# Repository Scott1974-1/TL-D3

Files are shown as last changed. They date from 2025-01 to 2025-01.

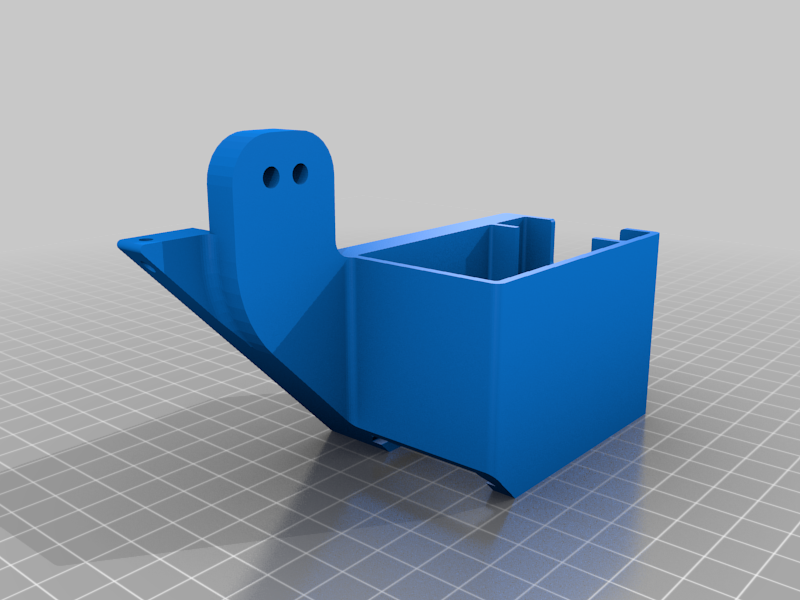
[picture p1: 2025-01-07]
Useful STL Files for the TL-D3 Pro /Purge Bin w_ Modular Inserts/images/TLD3pro_Purge_Bin.png

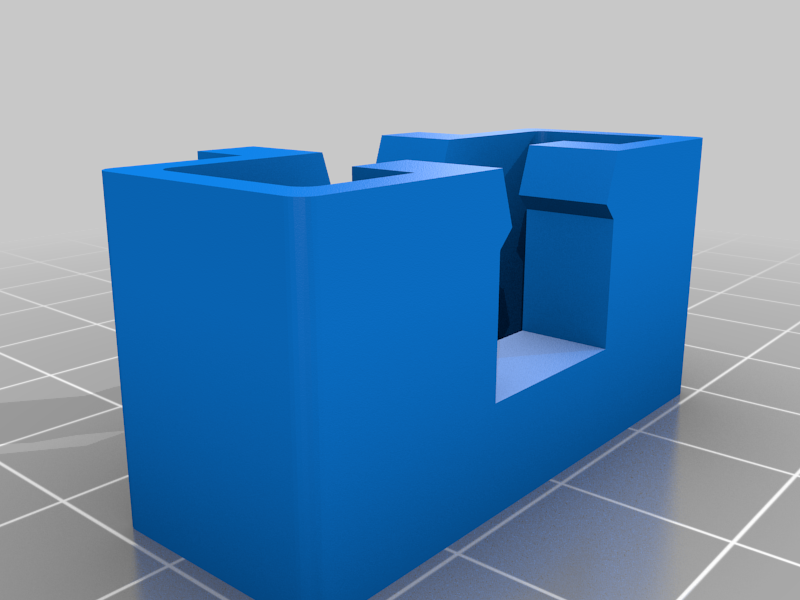
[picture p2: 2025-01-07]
Useful STL Files for the TL-D3 Pro /Purge Bin w_ Modular Inserts/images/TLD3pro_Purge_Bin_Brush_Insert.png

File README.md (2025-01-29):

# TL-D3 BUILD

This project will be coverting a stock Tenlog TL-D3 IDEX 3D printer into a fully upgraded machine running on Klipper firmware.<br>
The information collected in the GitHub is compiled from many different locations on the internet.<br>
The intent will be to build as complete of a collection of files, data and resources that are required to complete this project.<br>
<br><br><br>
Hardware used for this build:<br>
<br>
MCU = BTT Octopus Pro v1.1<br>
Steppers = 2209 v1.2<br>
CPU = Raspberry Pi 4b with 8GB ram & 256GB Sandisk Extreme Pro MicroSD Card<br>
Chassis = TenLog TLD3 Pro<br>
Display = TFT35 HDMI 3.5" touch screen<br>
Power = 24V Meanwell PS<br>
Camera = Logitech C270<br>
<br><br><br>
This will include the following upgrades:<br>
<br>
1- BTT Octopus Pro v1.1 MCU to replace the stock MCU.<br>
2- Installing 2209 v1.2 Stepper drivers onto the new MCU.<br>
3- installing a RPI as a main CPU running MainsailOS<br>
4- Installing a 3.5" color touch screen to replace the stock screen.<br>
5- Install the Camera for viewing prints and recording timelaps<br>
6- Install the extension cables for the MicroSD & USB connections from the RPI and Octopus board<br>
7- Rewire all the extruders, hotends, fans, and sensors to replace the old 15pin VGA cables used<br>
8- Install new custom extruder covers, sensor mounts<br>
9- Install custom 24v 5015 blowers to replace the old stock hotend & parts fans<br>
10- put bottom TPU foot extensions on the bottom of the case to give a bit more hight and airflow to the bottom<br>
11- Configuring the Printer in Klipper.<br>
12- Testing and completion.<br>
<br><br><br>
NOTES:<br>
See the cura profiles folder for all the cura profiles needed for the TL-D3 Pro. Very useful for getting cura setup. Works with Cura 5.9.0<br>
The STL's posted here are very useful for making your TL-D3 Pro more compatible of doing better cleaner prints. Plus a few extra STL files that will be good add-ons to the final build as well.<br>
The Images folder will have pictures in it of the build in progress. Before & after pictures also.<br>
<br>

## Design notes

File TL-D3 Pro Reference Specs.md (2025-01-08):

## Printer

### Chassis

[Tenlog TL-3D Pro](https://www.tenlog3d.com/tenlog-tl-d3-pro-independent-dual-extruder-dmp-3d-printer-with-touch-screen-support-pva-tpu-abs-pla-600w-version_p11.html)

| Machine Dimensions | Width | Depth | Height |
|---|---|---|---|
| Machine Size | 590mm | 520mm | 760mm |
| Build Volume | 300mm | 300mm | 350mm |

No mechanical modification on the printer except fitting of the screw domes for the new motherboard.

### Stepper driver

The [TMC2209](https://github.com/bigtreetech/BIGTREETECH-TMC2209-V1.2) has only Step/Dir mode and UART, **NO SPI**.  
Therefor the pins below the StepDriver are configured in UART mode:

```
oIoo
oIoo
oooo
```

The output voltage of the StepDriver should be the same as the supply voltage.  
Since the TCM2209 is not supporting other output voltages,
the jumper will use the 24V of the board:

```
o==
```

The TMC2209 supports StallGuard, which is connected to the diag pin.  
The StallGuard is overwriting the endstops, therefor they will not be used:

```
oooooooo
oooooooo
```

### Fans

The Fans are all 24V therefor the jumpers will bridge the last pins:

```
oo  5V
oo  12V
==  24V
```

### PT100 DIP Switch

The Tenlog 3D-Pro is using PT100 temperature sensors.  
Therefor all dip switches will be set to ON (which was default on my board).

### Power supply

To avoid powering the board via USB,  
the Power jumper in the center of the board needs to me removed.  
For installation and debugging I will keep it connected for now,  
But in production **I need to remove** the jumper!

### BLTouch

The BLTouch will be connected the flowing way:

```
ooooo
||||'-- white  [OUT] \ Sensor     > PB7
|||'--- black  [GND] /            x N/C
||'---- yellow [IN]  \            > PB6
|'----- red    [+5V]  | Controll  > 5VDC
'------ blue   [GND] /            > GND
```

### sub-D (DE-15)

#### E1/E2 Pinout

```
        Female               Male
   ,---------------.   ,---------------.
 5 \   o o o o o   / 1 \   * * * * *   / 5
10  \   o o o o o /  6  \   * * * * * / 10
15   \ o o o o o /  11   \ * * * * * /  15
      '---------'         '---------'
```

| 🟩 | Pin | Function |  | 🟩 | Pin | Function |
|----|-----|---|--|----|-----|---|
| ✅ | 1 | E 3 (C2) |  | ✅ | 3 | E 1 (C1) |
| ✅ | 6 | FZ - |  | ⬛ | 8 | LED + |
| ✅ | 2 | E 4 (C2) |  | ✅ | 14 | FC, FZ, H + |
| ✅ | 7 | FC - |  | ⬛ | ~~13~~ | *N/C* |
| ✅ | 9 | DJ |  | ✅ | 4 | E 2 (C1) |
| 🔀 | 10 | H - |  | ✅ | 5 | H - |
| ✅ | 11 | RH |  | ✅ | 15 | FC, FZ, H + |
| ✅ | 12 | DJ, RH, LED - |  |  |  |  |

| Function | Pins | Explanation |
|---|---|---|
| FZ | 6, 14, 15 | Hot-End Cooling (red/black) |
| FC | 7, 14, 15 | Part Cooling (yellow/blue) |
| RH | 11, 12 | Temp Sensor |
| DJ | 9, 12 | Filament Run-Out Sensor |
| E | 1, 2, 3, 4 | Stepper |
| H | 5, 10, 14, 15 | Heater |
| LED | 8, 12 | Blue LED |

### Fans

Seems like all fans can be connected directly.

#### Housing Fans

Use the 2 extra fan plugs (Fan4 & Fan5) in Controller Fan Mode.  
This disables the fans if there is no driver or MOSFETs in use.

# [Firmware](https://github.com/abangtor/Marlin4TL3DProWithOctopusPro)

## Stepper

| Plug | Driver | Axis |
|---|---|---|
| M0 | Driver 0 | X1 |
| M1 | Driver 1 | Y |
| M2.1/M2.2 | Driver 2 | Z1 |
| M3 | Driver 3 | Z2 |
| M4 | Driver 4 | E0 |
| M5 | Driver 5 | E1 |
| M6 | Driver 6 | X2 |
| M7 | Driver 7 | *NC* |

## Endstops/Filament

| Port | Plug | Axis | Mod |
|---|---|---|-----|
| PG6 | Stop 0 | X1 | Org:PSG > New:PGS |
| PG9 | Stop 1 | Y | Org:PSG > New:PGS |
| PG10 | Stop 2 | Z1 | Org:PSG > New:PGS |
| PG11 | Stop 3 | Z2 | Org:PSG > New:PGS |
| PG12 | Stop 4 | E0 | E1 sub-D 9 |
| PG13 | Stop 5 | E1 | E2 sub-D 9 |
| PG14 | Stop 6 | X2 | Org:PSG > New:PGS |
| PG15 | Stop 7 | *NC* |  |

## Fans

| Port | Plug | Fan |
|---|---|-----|
| PA8 | FAN0 | E0 Part Cooling Fan |
| PE5 | FAN1 | E1 Part Cooling Fan |
| PD12 | FAN2 | E0 Hot-End Cooling Fan |
| PD13 | FAN3 | E1 Hot-End Cooling Fan |
| PD14 | FAN4 | Housing Fan 1 |
| PD15 | FAN5 | Housing Fan 2 |

## Hot-Ends

| Port | Plug | Device |
|---|---|---|
| PA1 | Heated Bed | Bed |
| PA2 | HE0 | E1 |
| PA3 | HE1 | E2 |
| PB10 | HE2 | *N/C* |
| PB11 | HE3 | Casing Light |

## Buffers

Increased all buffers to the max to reduce lags in WiFi data transfer.  
Enabled XON/XOFF control characters.

```
#define BLOCK_BUFFER_SIZE 32
#define MAX_CMD_SIZE 96
#define BUFSIZE 32
#define TX_BUFFER_SIZE 256
#define RX_BUFFER_SIZE 2048
#define SERIAL_XON_XOFF
```

## Calibration

### PID Auto Tune

#### Bed

I run a PID Auto Tune with 9 cycles on the bed:

```
M303 C9 S60 D1 U1 E-1
```

With the new values the configuration is:

```
#define DEFAULT_bedKp 136.38
#define DEFAULT_bedKi 25.83
#define DEFAULT_bedKd 480.06
```

### Hotends

I run a PID Auto Tune with 9 cycles on both hotends:

```
M303 C9 S210 D1 U1 E0
M303 C9 S210 D1 U1 E1
```

With the new values the configuration is:

```
#define DEFAULT_Kp_LIST { 26.65, 24.61 }
#define DEFAULT_Ki_LIST {  3.00,  2.65 }
#define DEFAULT_Kd_LIST { 59.16, 57.10 }
```

### Step Driver Current

**TMC2209**  

$I_{RMS}=\frac{325\textup{mV}}{R_{sense}+20\textup{m}\Omega}\cdot\frac{1}{\sqrt{2}}\cdot\frac{V_{ref}}{2.5\textup{V}}$

|  Model | Length | Current | Resistance | Inductance | H.Torque | D.Torque |
|:---:|:---:|:---:|:---:|:---:|:---:|:---:|
| 17HS2408 | 28 mm  |  0.6 A  | 8 Ω | 10 mH | 12 N·cm  | 1.6 N·cm |
| 17HS3401 | 34 mm  |  1.3 A  | 2.4 Ω | 2.8 mH  | 28 N·cm  | 1.6 N·cm |
| 17HS3410 | 34 mm  |  1.7 A  | 1.2 Ω | 1.8 mH  | 28 N·cm  | 1.6 N·cm |
| 17HS3403 | 34 mm  |  0.4 A  | 30 Ω | 35 mH | 28 N·cm  | 1.6 N·cm |
| 17HS4401 | 40 mm  |  1.7 A  | 1.5 Ω | 2.8 mH  | 40 N·cm  | 2.2 N·cm |
| 17HS4402 | 40 mm  |  1.3 A  |  **2.5 Ω** | 5 mH | 40 N·cm  | 2.2 N·cm |
| 17HS8401 | 48 mm  |  1.7 A  | 1.8 Ω | 3.2 mH  | 52 N·cm  | 2.6 N·cm |
| 17HS8402 | 48 mm  |  1.3 A  |  **3.2 Ω** | 5.5 mH  | 52 N·cm  | 2.6 N·cm |
| 17HS8403 | 48 mm  |  2.3 A  | 1.2 Ω | 1.6 mH  | 46 N·cm  | 2.6 N·cm |

* X- & Z-Axis
  - 42-40 Motor (~3.2 Ω)
  - 1.3 A (- 10%) => 1170
* Y- & E-Axis
  - 42-48 Motor (~3.2 Ω)
  - 1.3 A (- 10%) => 1170

### UBL

1. Level bed manually on all 4 corners
2. Run  
   ```
   G0 Z10
   G30 X154 Y154
   ```
3. Read out result and calculate  
   $Z_{M851}=Z_{M851}-Z_{Probe}{\color{Gray}-Z{Paper}}$
4. Write probe offset with  
   ```
   M851 Z#.##
   ```
5. Run UBL
   ```
   M420 S0   ; disable bed leveling
   G28       ; home all axes
   M155 S30  ; reduce temperature reporting rate to reduce output pollution
   M190 S60  ; wait for the bed to get up to temperature
   G4 S60    ; wait another 1 min for the bed to reach temperature
   G29 P0    ; clear mesh
   G29 P1    ; automatically populate mesh with all reachable points
   G29 P3    ; infer the rest of the mesh values
   G29 P3    ; infer the rest of the mesh values again
   M420 S1 V ; enabled leveling and report the new mesh
   M500      ; save the new mesh to EEPROM
   M155 S3   ; reset temperature reporting
   M140 S0   ; cooling down the bed
   ```
6. Correct whole mesh with
   ```
   G29 P6 C#.##
   ```

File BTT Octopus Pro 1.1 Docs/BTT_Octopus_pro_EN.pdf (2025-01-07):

# BIGTREETECH

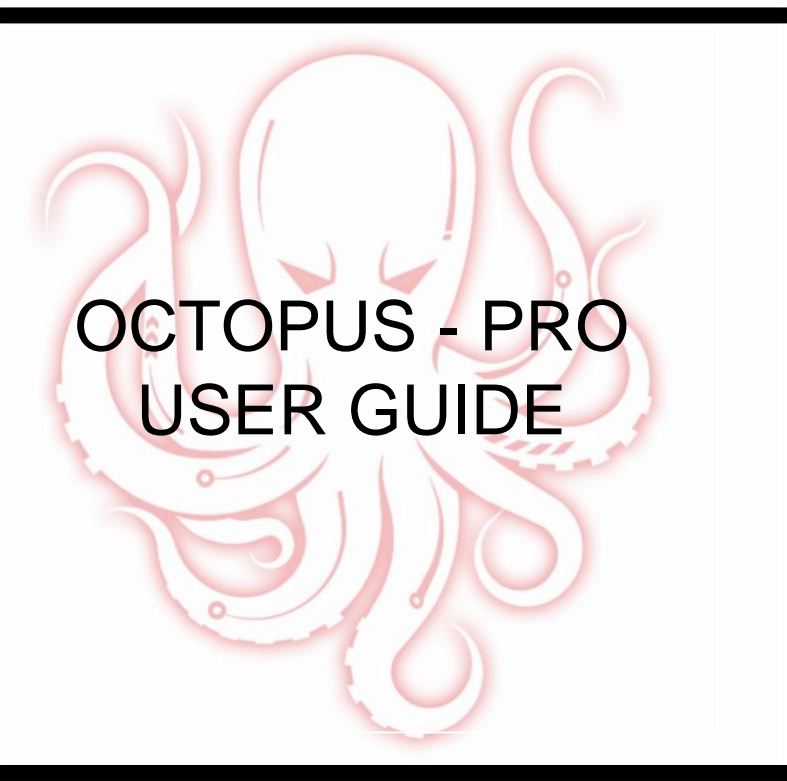
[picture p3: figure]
OCTOPUS - PRO USER GUIDE

Produced by BIGTREETECH

## October 18

2021

## Version 01.02

# TABLE OF CONTENTS

# DOCUMENT CHANGE HISTORY

VERSION | CHANGES | RELEASE DATE
01.00 | Initial release | 01/10/21
01.01 | Included the klipper config for the 429 variant | 12/10/21
01.02 | Various updates to pictures and wording correcting pin numbers. | 18/10/21

## 1 INTRODUCTION TO BIGTREETECH OCTOPUS-PRO V1.0

The BIGTREETECH Octopus-pro V1.0 is a powerful and feature rich, 3D printer motherboard that supports up to 8 60V stepper drivers with 9 stepper driver outputs in total. It is designed and manufactured by the 3D printing team of Shenzhen Bigtree Technology Co. Ltd

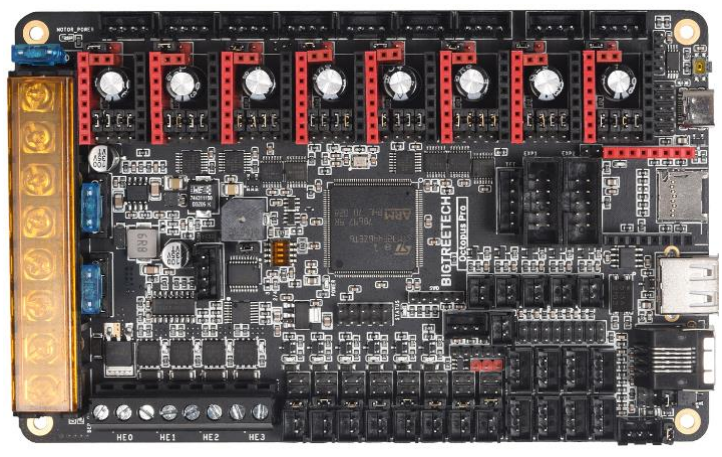
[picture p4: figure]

1.1 OCTOPUS-PRO MOTHERBOARD FEATURES

1. Uses a 32-bit ARM Cortex-M4 series. Option A comes with an STM32F446ZET6

main control chip with a core frequency of 180MHz and a flash capacity of 512kB.

Option B comes with an STM32F429ZGT6 with a core frequency of 168MHz and a

flash capacity of 1MB. For Klipper use, option A is likely sufficient.

2. Supports running Klipper, Marlin and RRF.
3. Voltage selection jumpers for each motor driver allow the user to independently

select the voltage routed to that driver. Select between the dedicated motor voltage

input (up to 60V) and the main logic input (24V).

4. Interfaces with a Raspberry Pi using emulated serial over USB or direct UART to any

of the serial ports on the board.

5. Supports up to 4 hotend heaters.
6. Provides separate power inputs for motors, bed heating and logic/fans/hotends.
7. Supports 12V or 24V supply inputs (12V only supported on motor and bed. Logic

must be > 14.1V and < 28V) with built in 12V (4A), 5V (8A) and 3.3V (1A) regulators

to provide rails for peripheral use.

8. Up to 6 PWM fans and 2 always-on fans with the ability to individually select the

voltage rail that will drive each fan. Select from Vin, 12V or 5V.

9. Flyback protection on PWM fan ports – Many people find that their fan ports become

damaged after some time when using larger fans. This is because of the inductance

in the fan coils. The octopus includes flyback protection on each fan port which will

protect the FETs from damage caused by turning the fans on and off.

10.Includes USB-C interface which supports an emulated serial port that allows printing

via USB.

11.Supports all versions of BIGTREETECH TFT screens and LCD12864 screens.

12.Supports multiple languages such as English and Simplified Chinese and can easily

switch between different languages (when using the BTT TFT).

13.Includes a bootloader that allows firmware upgrades via the SD card. This offers a

simple, efficient, and convenient way to update the firmware.

14.Uses high-performance MOSFETs to increase heating efficiency while also reducing

heat generation on the motherboard.

15.Uses easily replaceable fuses

16.Supports “print from SD card” and “print via USB OTG” using the integrated USB-A

port.

17.Provides two stepper outputs, connected in parallel, to the Z driver allowing for a

parallel, dual Z axis drive.

18.Supports firmware update via DFU mode. This is where the firmware is sent to the

board directly from the PC and does not require a bootloader however this method is

not recommended for novice users as discussed later in this document.

19.Includes an onboard, 32K EEPROM (AT24C32).

20.Provides an RGB LED interface.

21.Provides a WiFi interface for ESP8266 based modules.

22.Provides a built-in PT100/1000 interface using an integrated MAX31865 amplifier.

The interface supports 2/3/4 wire connections.

23.Thermistor input protection. This allows you to short a thermistor input directly to a

voltage source (not that this makes it a good habit to pick up) up to Vin without

causing damage to the motherboard.

24.Supports BL Touch and various other ABL sensors.

25.Provides a dedicated “PROBE” port for bed probes. This port is internally protected

via an optocoupler which means that you don’t need to use a BAT85 diode.

Additionaly, the octopus-pro includes a pull up resistor on the probe port which can

be selected or deactivated using a jumper. This allows it to work with both NPN and

PNP type probes.

26.Supports CAN BUS using a 6P6C RJ11 interface, which offers the board the ability

to interface with future expansion modules.

27.Supports StallGuard for sensorless homing with TMC drivers

28.Provides an SPI expansion port which can connect the SPI-based expansion

modules.

29.Supports the shutdown after printing function.

30.Supports the power loss print resume function

31.Includes inputs for up to 6 endstop switches and 2 filament runout interfaces.

32.Provides an I2C expansion port for peripherals that communicate using that protocol.

33.Includes a short circuit warning buzzer which will provide an audible alert when the

current load on the 5V rail is exceeding what the regulator is able to produce.

1.2 OCTOPUS-PRO MOTHERBOARD PARAMETERS

1. Edge to edge size: 160*100mm
2. Mounting hole to hole size: 150*90mm
3. Microprocessor: | ARM | 32-bit | Cortex™-M4 | CPU: | STM32F446ZET6 | OR

STM32F429ZGT6

4. Recommended motherboard input voltage: DC15V – 28V
5. Motor input voltage range: DC12-60V
6. Bed input voltage range: DC12-28V
7. Motor drivers: Pluggable drivers supporting all popular driver types.
8. Motor driver sockets: MOTOR0, MOTOR1, MOTOR2_1, MOTOR2_2, MOTOR3,

MOTOR4, MOTOR5, MOTOR6, MOTOR7

9. Temperature sensor interfaces: TB, T0, T1, T2, T3.

10.Display interfaces: BIGTREETECH TFT touch screen, LCD12864, LCD2004, etc.

11.PC communication interfaces: USB Type-C with configurable BAUD.

12.Expansion interfaces: Filament runout, power loss detection, automatic power down,

BL Touch and many others.

13.Supported print file format: G-code or whatever the firmware under use supports.

14.Recommended slicing/interface software: Cura, IdeaMaker, Simplify3D, Prusa Slicer,

Pronterface, Repetier-host, Makerware, etc…

## 2 MOTHERBOARD WIRING

Note: The octopus-pro packs a ton of features which necessitates many components and connectors. Given the component and connector density it was not possible to include the silk screen for connector labels on the top. We recommend that you snap a picture of the bottom of the board before starting the installation so that you have a label reference on hand. If you forget to do so then you can always make use of the PINS.pdf file available on our github repo. (https://github.com/bigtreetech/BIGTREETECH-OCTOPUS-Pro)

2.1 POWER WIRING

The octopus pro provides three separate power inputs: motherboard power, motor power, and bed heater power. This allows a user to use several power supplies with common grounds in order to ensure that they are able to provide the required power to each part of their system. The motherboard power is regulated using a number of switch-mode and low dropout power supplies to provide the supply rails of 12V, 5V and 3.3V.

The 12V, 5V and 3.3V rails are made available via various pins on the motherboard. Consult the PINS.pdf document to find a breakout header if you plan to use one of these supply rails. Take note that the 12V rail can supply up to 4A, the 5V up to 8A and the 3.3V up to 1A however, in order to prevent overloading the rails it is not recommended to load them to their maximum capacity since there are already various components on the motherboard which also take their supply from them.

Power wiring is as shown below (look on the underside of your board to quickly identify the purpose of each input if the pins file is not on hand). The positive (red) wire from the power supply goes to the terminal marked +. The negative (black) wire from the power supply goes to the terminal marked -. The polarity (+ and -) is also silk screened onto the underside of the board.

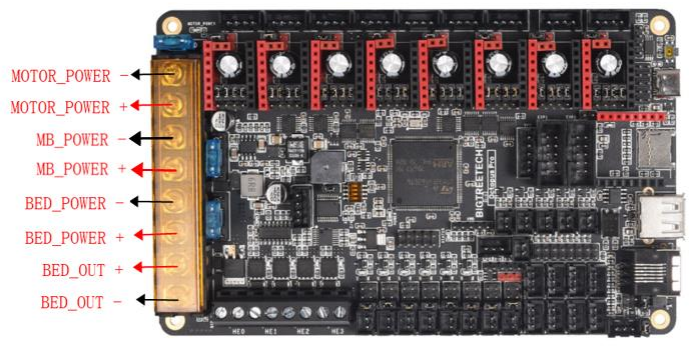
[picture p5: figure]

Note: DO NOT alter the board wiring with the power on and be sure to get the polarity correct otherwise you can damage the motherboard.

2.2 AUTOMATIC POWER DOWN WIRING

When using the BIGTREETECH Relay V1.2 module, the wiring can be performed as shown in the figure below.

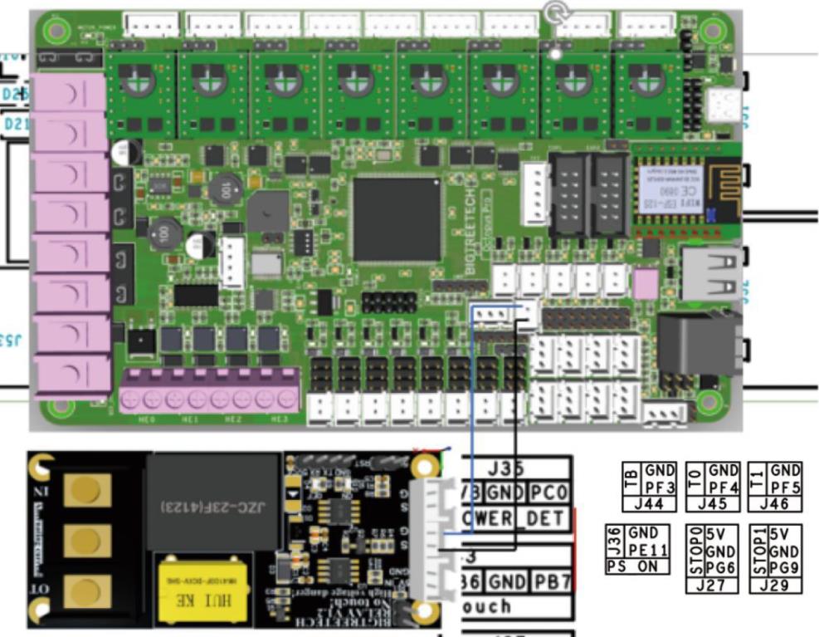
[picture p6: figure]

Note: Since power will still be supplied to the Relay 1.2 module after it has cut power to the motherboard, it is extremely dangerous to touch the it while the printer is still connected to mains. Always remove all mains power when working on this wiring.

2.3 BL TOUCH WIRING

When using a BL Touch, wire it to the motherboard as shown in the figure below. As always, never perform any work on the motherboard with power applied.

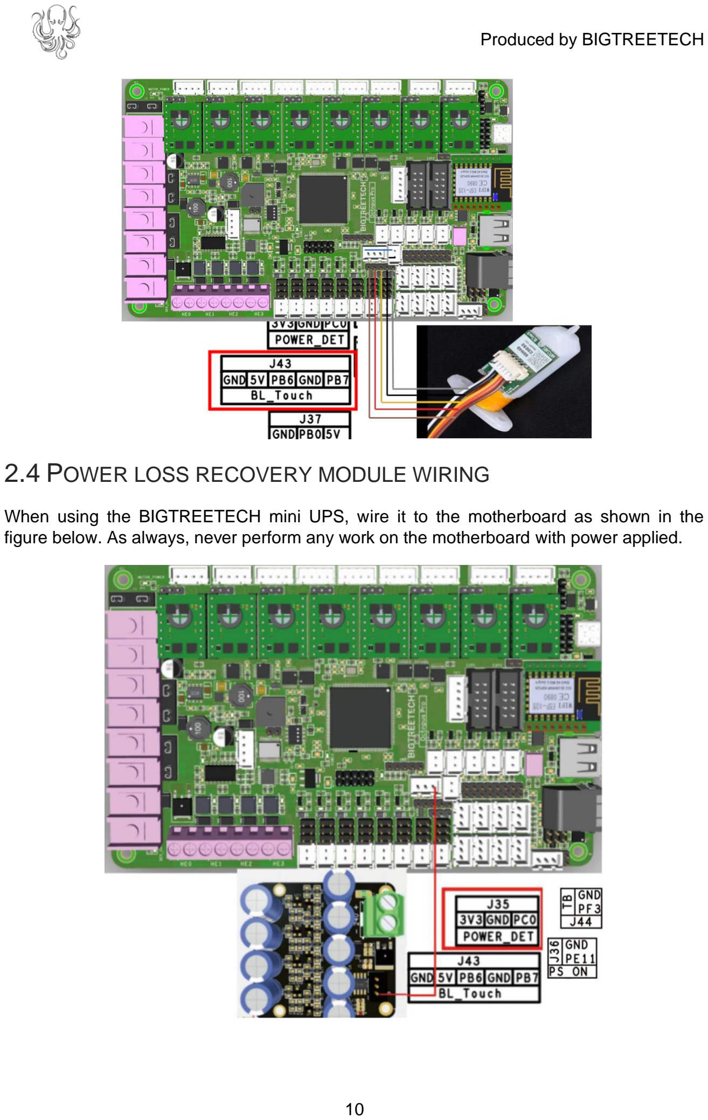
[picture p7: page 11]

2.4 POWER LOSS RECOVERY MODULE WIRING

When using the BIGTREETECH mini UPS, wire it to the motherboard as shown in the figure below. As always, never perform any work on the motherboard with power applied.

## 2.5 RGB LED WIRING

When using the motherboard with RGB LEDs you should wire them as shown in the image below. The exact pinout of the connector can be found on the silkscreen on the underside of the motherboard.

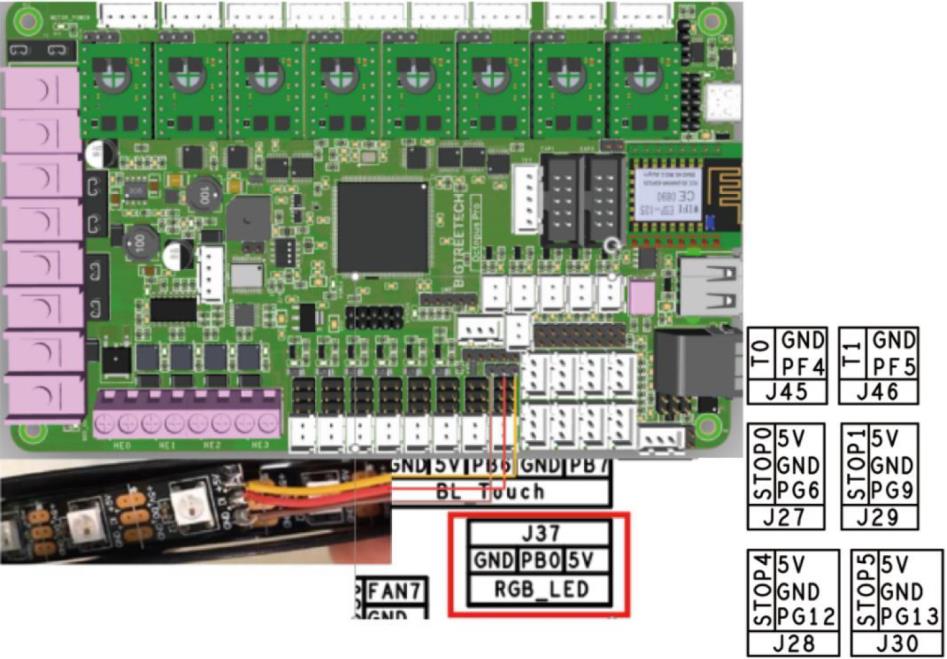
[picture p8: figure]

2.6 RASPBERRY PI WIRING

The motherboard supports a connection to a Raspberry Pi for printing. There are several connection options available to connect to a raspberry pi. Simplest of all is to connect the raspberry pi directly to the USB-C port which will emulate a virtual serial port on the pi. However, if you have another need for the USB-C port you are still able to connect the raspberry pi to the motherboard using a direct serial connection over UART or SPI.

Dedicated UART and SPI pin headers have been made available on the motherboard for this purpose with the pin mappings conveniently printed in silkscreen on the underside of the board for each. It is beyond the scope of this manual to detail exactly how to connect the raspberry pi to either of these headers however there is an abundance of material online that explains how to interface a raspberry pi to an external device over either of these serial busses.

5V power for the raspberry pi is provided via the dedicated Raspberry pi header (UART2). Consult the PINS.pdf document for the exact pinout of this header.

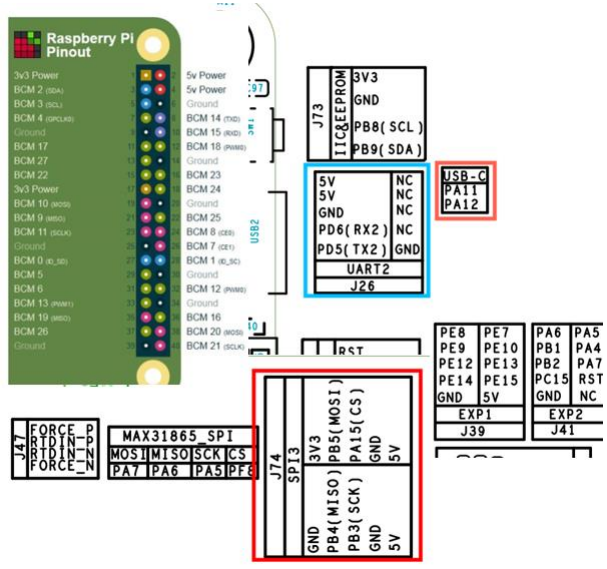
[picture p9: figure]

2.7 PROBE PORT WIRING

The probe port has been provided to allow users to interface bed probes directly to the motherboard without the need for a BAT85 diode to act as a protection against high voltages. The probe signal pin connects to an internal optocoupler that in turn triggers the pin connected to the microcontroller.

Depending on the type of probe you are using, you may need to add a jumper to activate the internal 12k pull up resistor between the probe positive voltage rail and the probe signal pin. This will be the case if you are using an “NPN” style probe where the output pulls to ground when it is active. You can tell this by checking the output of your probe using a multimeter. If it floats when it is not active (with nothing else connected to it) and then goes to ground when it is active, it is an NPN style probe. If it goes to the positive rail when active then it is a PNP style probe. The image below shows where the jumper to activate the 12k pull up resistor is located.

Regardless of the kind of probe you are using, you will need to enable the internal pull-down resistor on the probe input pin in order for it to generate an output signal. Please refer to the pin configuration instructions for the specific firmware that you are using to find out how to enable a pull down resistor on the probe input pin (PC5).

Refer to Section 4.2 for further information on how to configure the voltage used by the probe port.

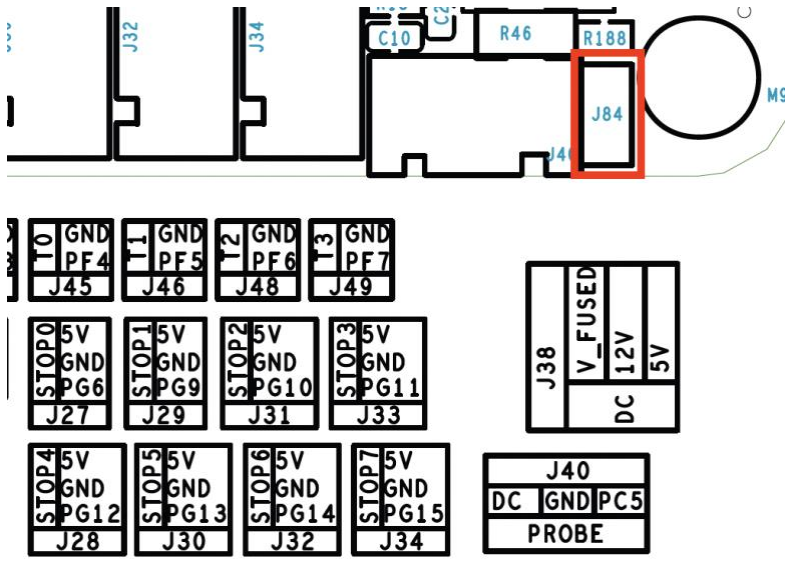
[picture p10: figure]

## 3 STEPPER DRIVER OPERATIONAL MODES

3.1 STEP/DIR MODE

If you are using drivers that do not support configuration over a serial port then you will need to operate them in step/dir mode and set the jumpers beneath the stepper driver according to the microstepping you desire.

Each driver will have its own microstepping table so we do not attempt to speak on behalf of the driver manufacturer in our manual. Please consult the datasheet of your driver to determine what signals need to be applied to the microstepping configuration pins in order to achieve the microstepping you desire.

Nevertheless, below you will see a figure which will help you to identify which jumpers correspond to the pins that your drivers will use to configure microstepping and we have additionally included a section in appendix A1 which contains the microstepping tables for some of the most common drivers. This should be viewed as a convenience to the user and we still recommend that you consult the datasheet of your driver manufacturer.

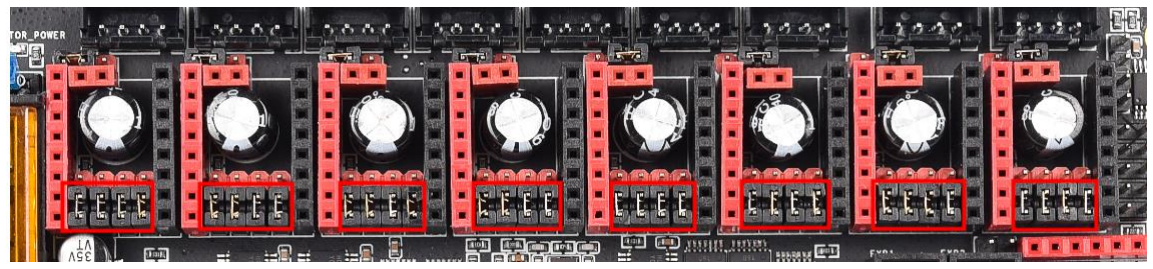
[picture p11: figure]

In the above image the red rectangle isolates the groups of driver pins. For the purpose of running the drivers in step/dir mode the pinout can be described as per the table below (note that this is not the actual pinout but rather a simplification for step/dir mode).

NA | NA | NA | NA
RST | MS3/2 | MS2/1 | MS1/0
SLP | 5V | 5V | 5V
Connecting jumpers between the lower two rows will set the middle pin (MS) to 5V except for the jumpers in the first column where it will connect SLP and RST. Note that if your stepper driver requires 0V to be present on any of the pins then there is actually no need to connect a jumper to that pin when running in step/dir mode and connecting a jumper in this instance could cause interference since those lines are used for the SPI bus.

Note that if you use an A4988 or a DRV8825 driver, you must connect RST and SLP.

## 3.2 UART MODE

When using a driver in UART mode, connect the jumpers beneath that driver as show in the image below.

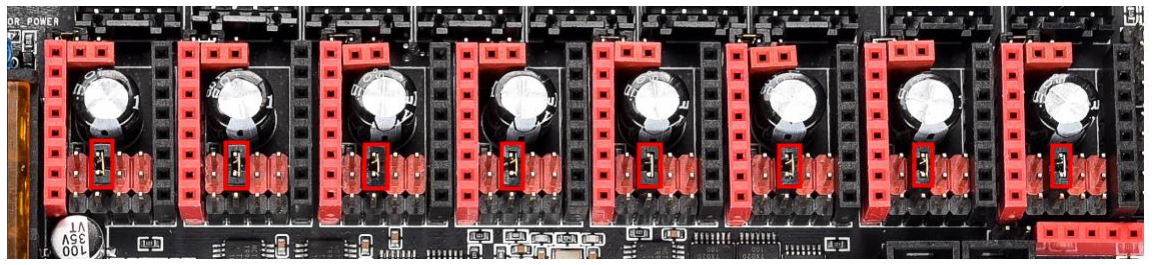
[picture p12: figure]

## 3.3 SPI MODE

When using a driver in SPI mode, connect the jumpers beneath that driver as shown in the image below.

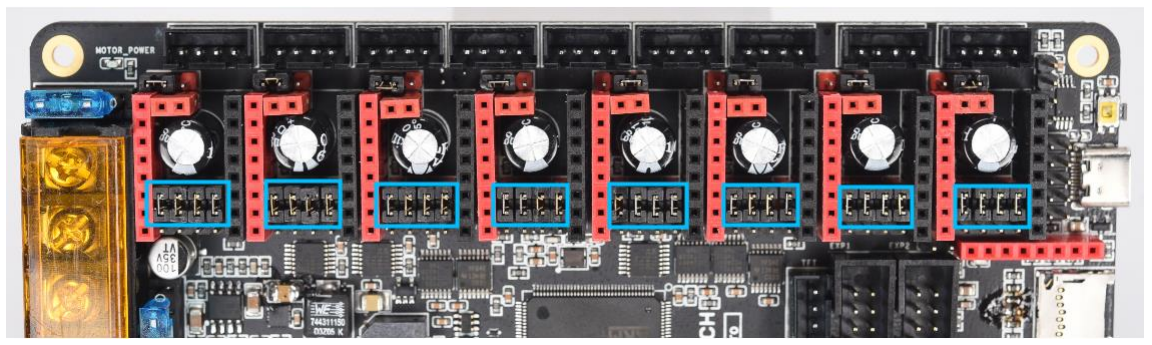
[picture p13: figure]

## 4 MOTHERBOARD JUMPER SETTINGS

4.1 MOTOR POWER SELECTION JUMPERS

Each motor driver on the octopus pro can have the voltage used by it configured via a jumper.

Note: Before powering your octopus pro, always double check the driver voltage jumpers to ensure that the correct voltage is being routed to each driver. Sending a high voltage to a driver that is not rated for it is likely to destroy it and may even cause damage to the motherboard.

Setting the jumper for any given driver to the right, as shown in the image below, will provide the motherboard input voltage for that driver to use. Generally the motherboard uses 24V.

Setting the jumper for any given driver to the left, as shown in the image below, will provide the motor input voltage for that driver to use. This can be up to 60V.

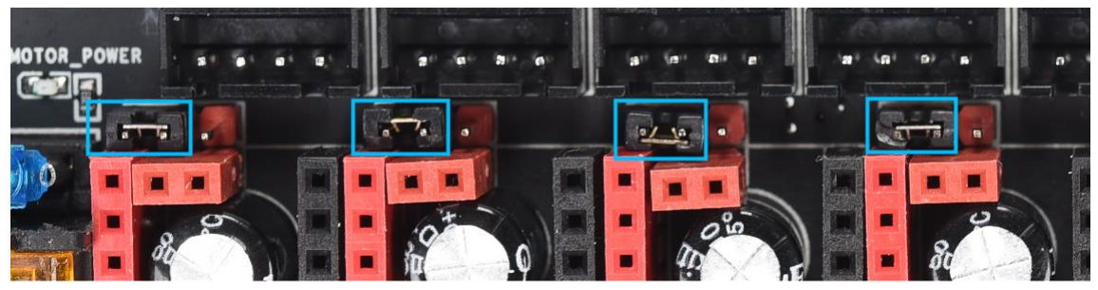
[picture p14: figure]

Note: Never remove or insert a jumper when power is applied to either the board input or the motor input.

4.2 FAN AND PROXIMITY SWITCH VOLTAGE SETTINGS

The Octopus features 6 PWM fan outputs and two “always on” fan outputs. There is also a dedicated pin header for a proximity sensor or probe.

All of the fan outputs and the proximity sensor input can individually have the voltage supplied by their pin header selected by configuring the jumpers associated with each header.

Configure the jumpers as below to select 24V (note that all are shown in the same configuration even though they can be individually configured).

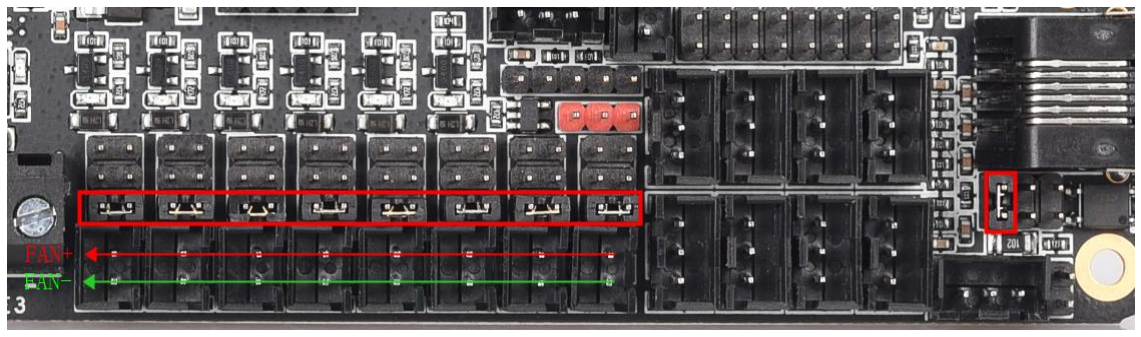
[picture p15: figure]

Configure the jumpers as below to select 12V.

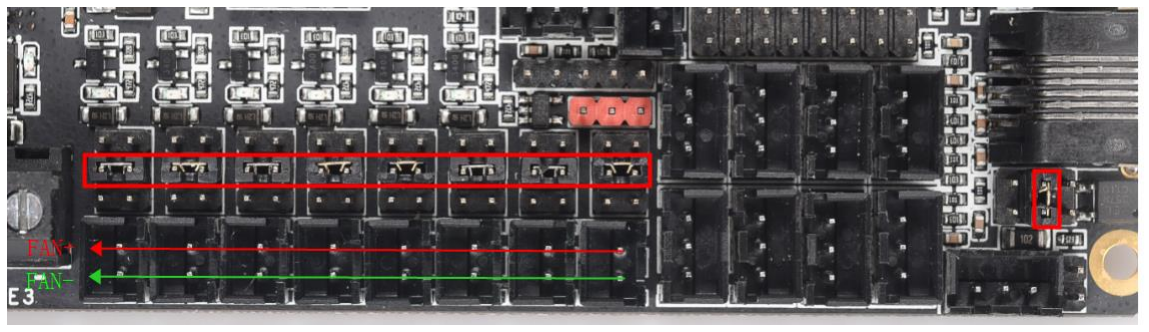
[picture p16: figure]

Configure the jumpers as below for 5V.

Note: Since the jumpers carry a voltage rail directly from one of the regulators

or from the input, if you short the jumpers in any way other than the shown

connections, you will likely cause damage to the motherboard. When

connecting the fan, make sure that you connect the positive terminal to the

positive output as shown in the images.

4.3 STALLGUARD JUMPER SETTINGS

The “diag” jumpers which are used to connect the diagnostic output pin to the endstop inputs for drivers which support the stallguard feature (TMC2209/TMC2226, etc…) can be found in the location shown in the image below.

The exact diag numbering can be found by looking at the pins file or the silkscreen beneath the board.

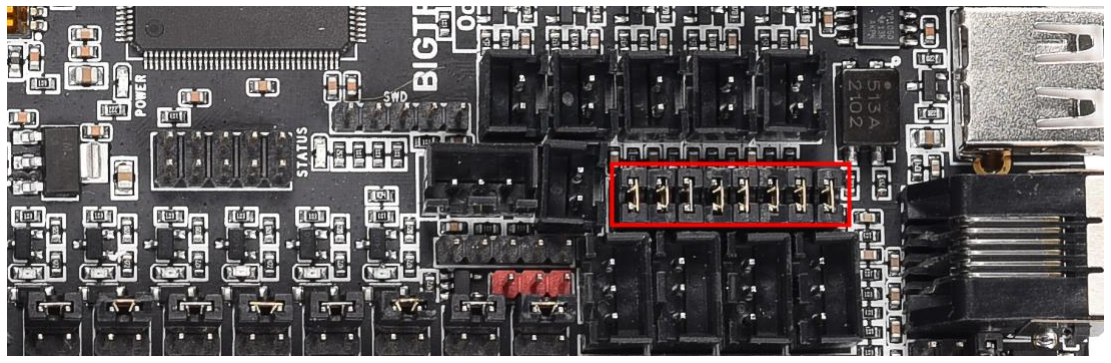
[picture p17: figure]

4.4 MCU POWER JUMPER

The Octopus can be powered using the USB-C port by inserting the jumper as shown below. This can make it easier to compile and download firmware directly to the motherboard using DFU mode.

If you do not connect this jumper then you must provide the board with power via the main input supply if you would like to communicate via USB-C.

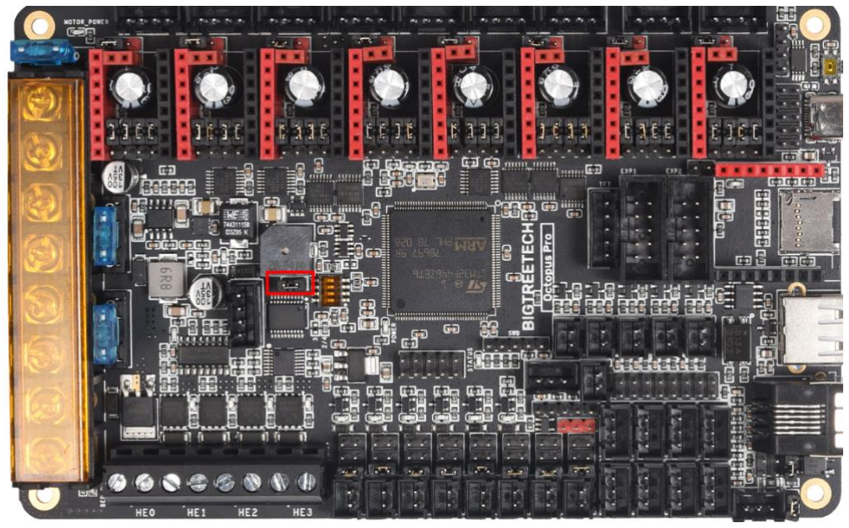
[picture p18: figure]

## 4.5 PT100/PT1000 DIP SWITCHES

The PT100 amplifier supports 2,3 and 4 wire connections to the board. However, the DIP switch needs to be configured for the setup that you are using.

You can find the DIP switch in the location shown in the image below. Note that the DIP switch has switch numbers and the “on” position printed on it.

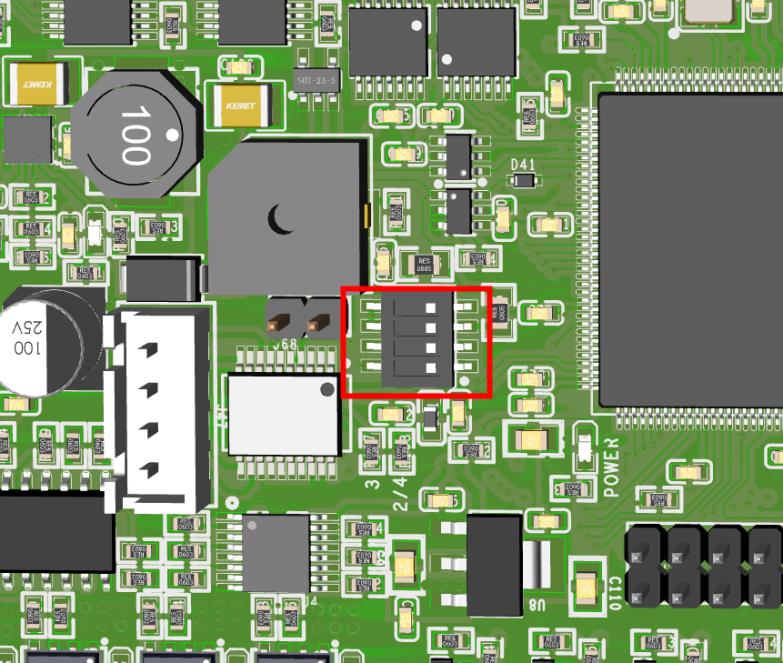
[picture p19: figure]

Select the connection arrangement for your thermistor according to the table below. Bear in mind that you will still need to configure your firmware using the correct sense resistor values which will be 430Ω for the PT100 and 4300Ω for the PT1000.

1 | 2 | 3 | 4 | Sensor model
ON | ON | ON | OFF | Two-wire PT100
ON | ON | OFF | ON | Two-wire PT1000
OFF | ON | ON | OFF | Three-wire PT100
OFF | ON | OFF | ON | Three-wire PT1000
OFF | OFF | ON | OFF | Four-wire PT100
OFF | OFF | OFF | ON | Four-wire PT1000

If you are using a three-wire arrangement, then you will also need to make a small adjustment to an SMD resistor on the board. The image below shows the factory default resistor setting in the blue box (2/4 wire arrangement). Using a 3 wire arrangement will require you to move the resistor from the blue box into the red box and then to leave the pads in the blue box unpopulated. These resistors are 0Ω so if you do not feel comfortable soldering them back in place you can always just create a solder bridge between the pads instead, selecting the pads appropriate to your arrangement.

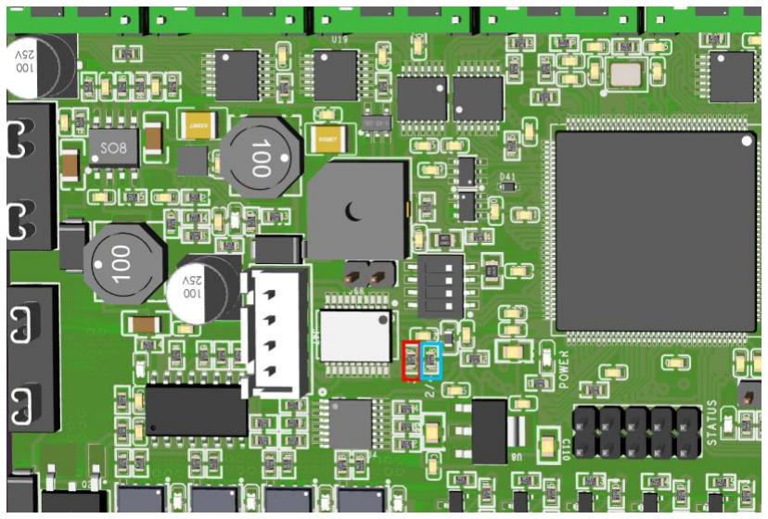
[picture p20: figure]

## 5 MOTHERBOARD PHYSICAL SPECIFICATIONS

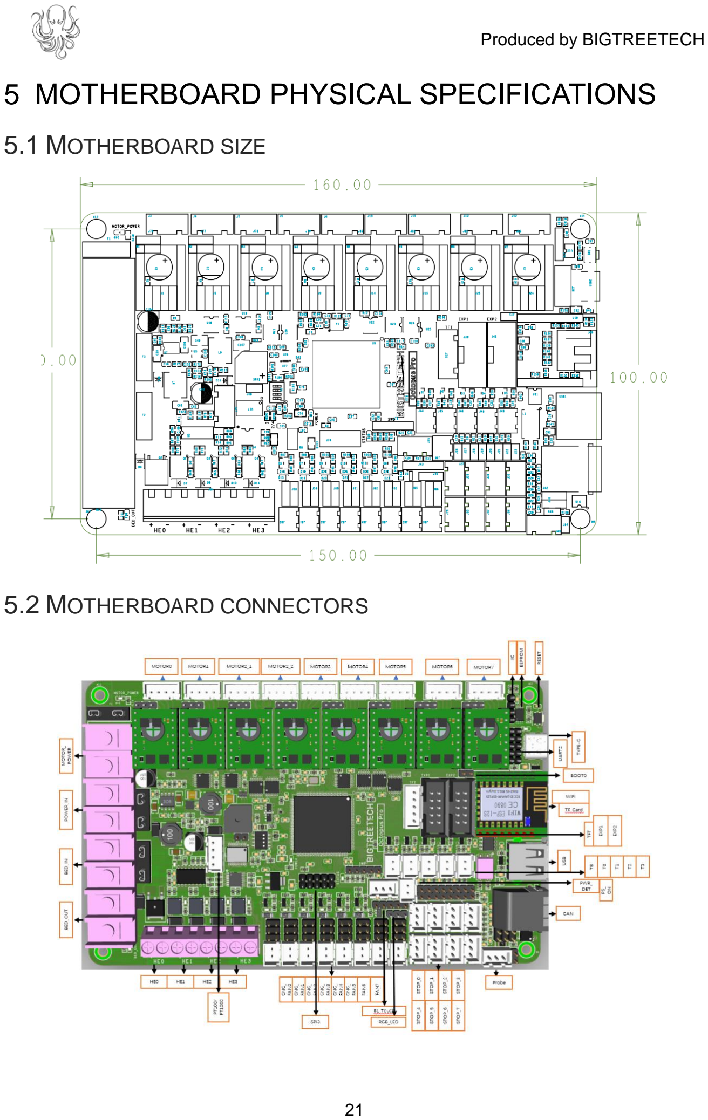
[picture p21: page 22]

5.1 MOTHERBOARD SIZE

5.2 MOTHERBOARD CONNECTORS

5.3 MOTHERBOARD PINS

The image below is a snippet taken from the PINS.pdf document. For better viewability please consult the PINS.pdf document.

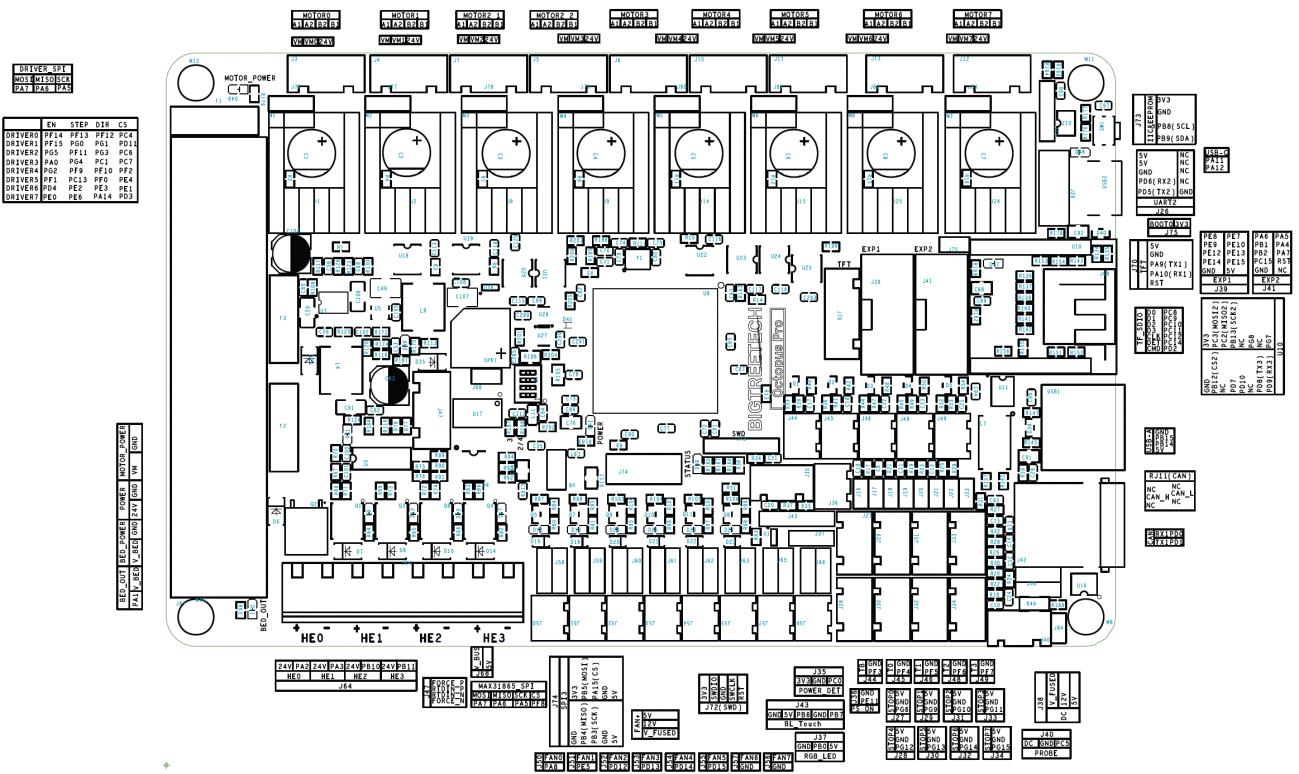
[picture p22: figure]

## 6 COMMUNICATING WITH THE MOTHERBOARD

After connecting the motherboard to a computer via a USB cable, the driver will be automatically installed (windows, linux and macos). Upon installation of the driver the motherboard should automatically enumerate as a virtual serial device which can be used for data transfer. If it fails to do so, you can visit our GitHub website: https://github.com/bigtreetech?tab=repositories and find the corresponding repository to download the driver.

If you would like to confirm that the driver has been installed correctly you can access the device manager in windows and look for a virtual com port when the motherboard is plugged in. In the image below the motherboard has been assigned COM7 however your operating system may assign it any available COM port number. Other operating systems will list serial ports in a different manner.

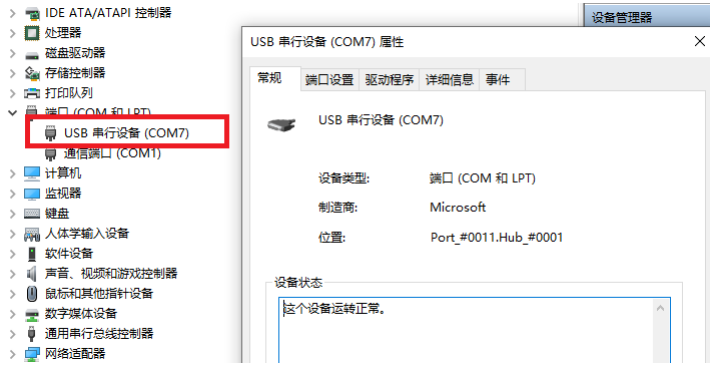
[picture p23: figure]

## 7 MOTHERBOARD FIRMWARE SUPPORT

Marlin, Klipper and RRF (429 variant) all support the Octopus Pro. You can compile and configure you firmware variant of choice according to the methods specified by the developers of that firmware. In time, configuration files for different firmware distributions will be made available on the octopus-pro github. (https://github.com/bigtreetech/BIGTREETECH-OCTOPUS-Pro) Covering how to compile firmware using VSCode is beyond the scope of this manual however there is an abundance of information online which explains how to set up VSCode on your machine and how to configure Marlin thereafter. Good places to start are provided for your convenience in the links below:

- https://marlinfw.org/docs/basics/install_platformio_vscode.html
- https://www.youtube.com/watch?v=eq_ygvHF29I

Once you have either compiled your own version of Marlin or downloaded a pre-compiled version, you can install it by following the steps below:

1. Make sure that the firmware binary is named “firmware.bin”. Any other name will be

rejected by the bootloader.

2. Use an SD card that has been formatted using the SD formatter tool here:

https://www.sdcard.org/downloads/formatter/

3. Copy the firmware binary file to the SD card.
4. Insert the SD card into the motherboard and reset it.
5. Remove the SD card and check that the file has changed name to

“FIRMWARE.CUR”. This will confirm that the firmware was successfully installed.

If you are using Klipper then please ensure that you have the following settings enabled for the 446 variant. Take careful note of the crystal oscillator frequency which is 12MHz and differs from the 429 variant.

The 429 variant of the board makes use of a different frequency crystal oscillator (8MHz) and therefore the klipper configuration needs to be adjusted slightly as show in in the image below.

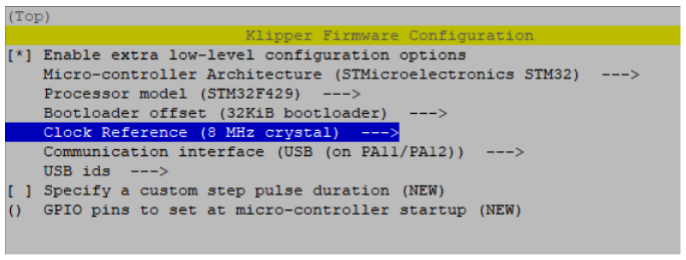
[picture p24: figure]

## 8 PRECAUTIONS

The precautions listed in this section should not be overlooked. They have been included as reminders to prevent damage to your motherboard.

1. Never work on the motherboard with power applied.
2. Always double check all jumpers and wiring before applying power. Improper

jumpers or wiring can cause damage to the motherboard and possibly even

peripherals that it interfaces with.

3. The motherboard can power heated beds up to 300W. If you are using a bed that

operates at a higher power then you will need to use an external MOSFET. Do not

connect a voltage source greater than 28V to this input.

4. Never short circuit the 3.3V, 5V, 12V or 24V supplies to each other. Doing so will let

out some smoke and BTT will not be able to put it back for you.

5. You cannot power external devices using the USB-C interface. It is designed for data

only.

6. Always consult the PIN.pdf diagram when making jumper connections or wiring

changes. Assuming a connection order may result in damage to the motherboard.

7. It is recommended to update the firmware using SD card. Using DFU (direct

programming via the USB port) will overwrite the bootloader meaning that you will no

longer have the option to update via SD card unless you reflash the bootloader.

## 9 A THANK YOU FROM BIGTREETECH

If you encounter problems when using the Octopus, please contact BIGTREETECH and we will be glad to assist. You can find our latest support contact details at our website: https://www.bigtree-tech.com/.

If you have any comments or suggestions on this or any of our other products then please reach out to us via our support channels and we will be glad to take your thoughts into consideration.

We appreciate your support and hope that you enjoy using your new Octopus motherboard.

The BIGTREETECH team.

# APPENDICES

## A1. COMMON DRIVER JUMPER TABLES

These tables are provided as a convenience to the user. Since we cannot speak on behalf of the manufacturer of your drivers it is recommended that you still find the datasheet for your drivers and reference the pin settings required for the microstepping factor that you desire. Note that the pin naming and ordering in the tables below is not consistent but the lowest number pin will always map to the pin named MS1 on the octopus and the numbering follows from there.

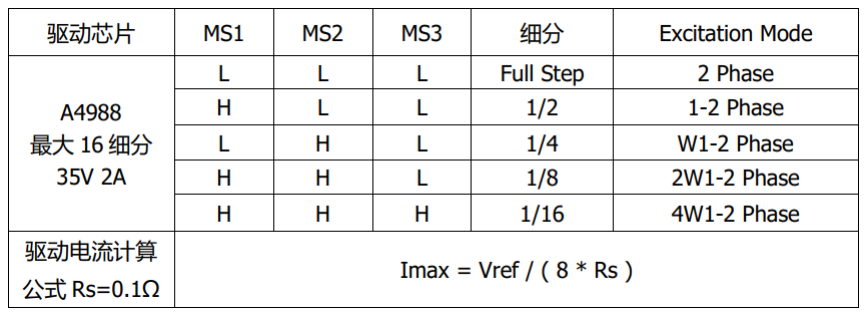
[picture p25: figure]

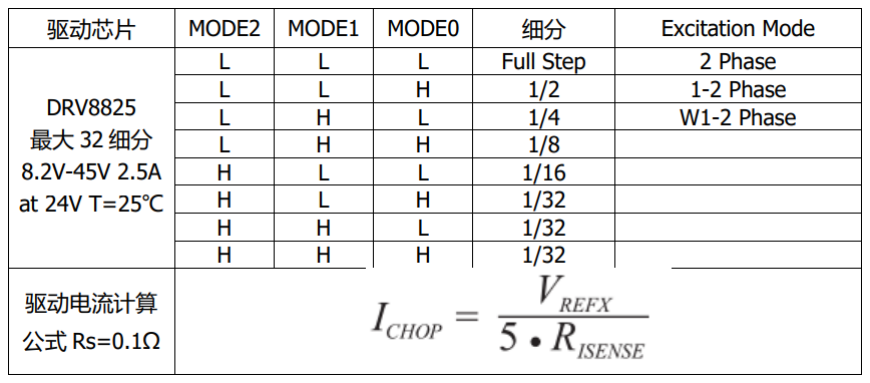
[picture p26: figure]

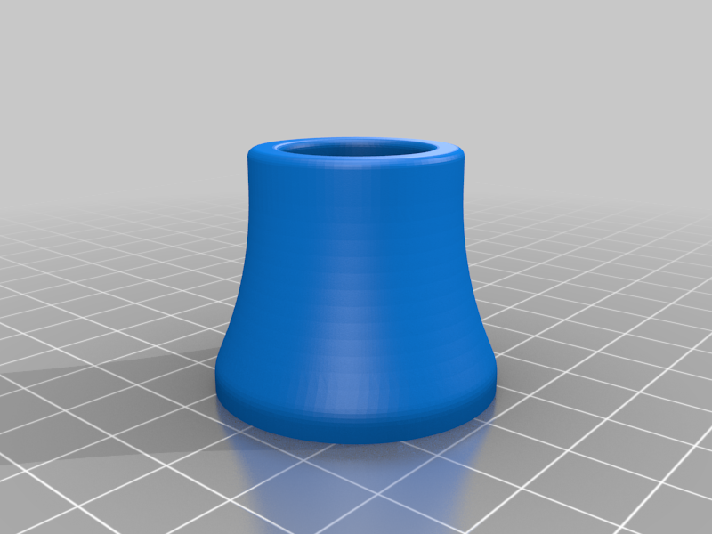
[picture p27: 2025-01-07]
Useful STL Files for the TL-D3 Pro /Tenlog TL-D3 Pro TPU Foot/images/Tenlog_TL-D3_Pro_TPU_Foot.png

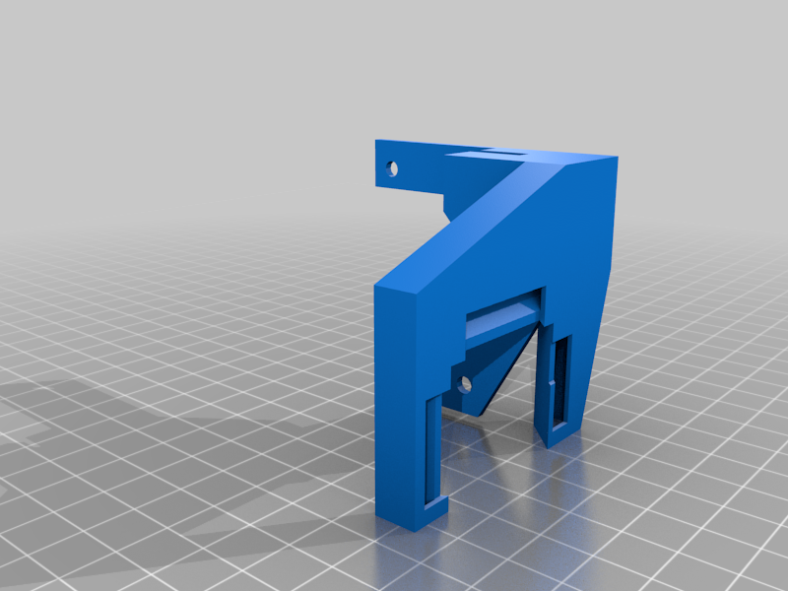
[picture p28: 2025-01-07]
Useful STL Files for the TL-D3 Pro /5015 Fanduct/images/DC_T1_fanduct.png

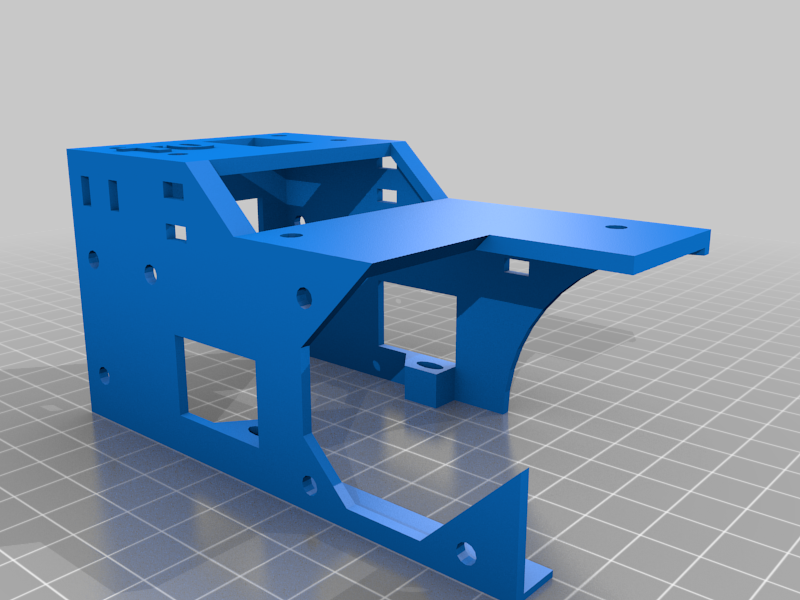
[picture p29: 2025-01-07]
Useful STL Files for the TL-D3 Pro /5015 Fanduct/images/T0_cover.png

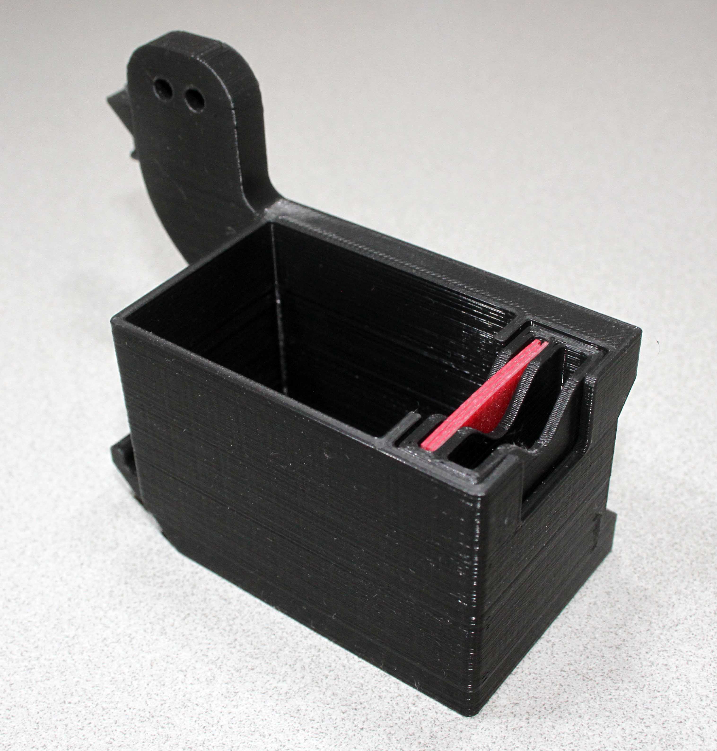
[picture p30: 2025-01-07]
Useful STL Files for the TL-D3 Pro /Purge Bin w_ Modular Inserts/images/TLD3pro_Purge_Bin_4.jpg

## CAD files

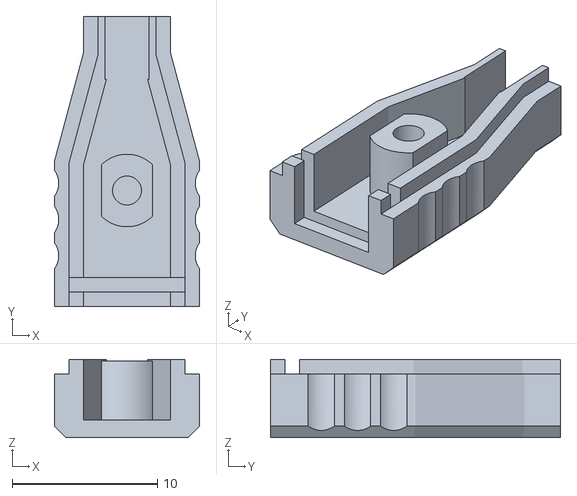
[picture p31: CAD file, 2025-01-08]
Useful STL Files for the TL-D3 Pro /JST-XH Protectors /2pin/JST_Main2P-c2.stl
10.0 x 20.0 x 5.40

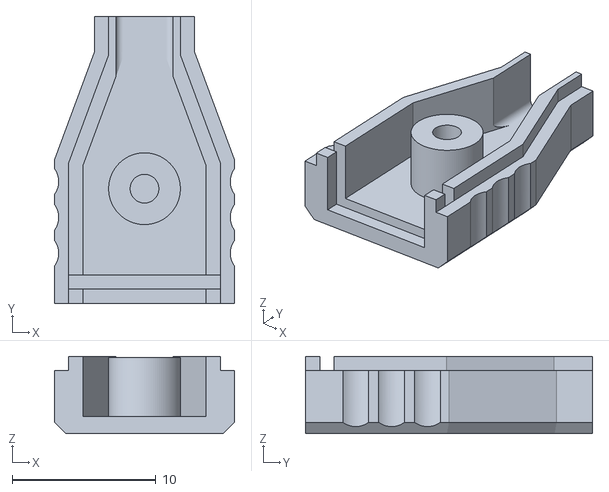
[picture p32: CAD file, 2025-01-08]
Useful STL Files for the TL-D3 Pro /JST-XH Protectors /3pin/JST_Main3P-c3.stl
12.6 x 20.0 x 5.40

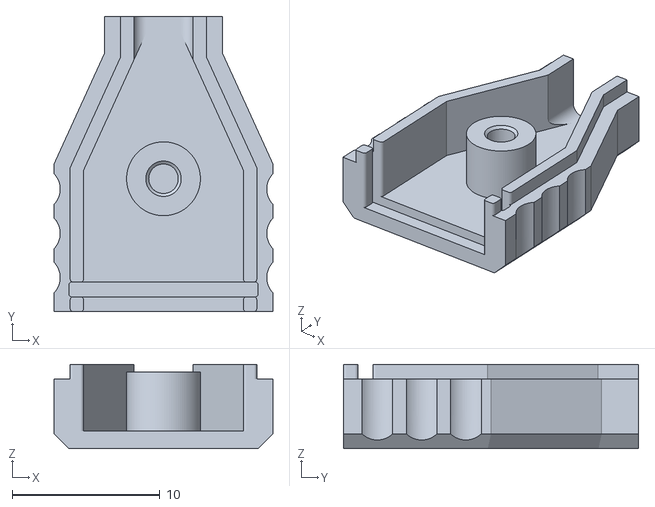
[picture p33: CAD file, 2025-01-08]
Useful STL Files for the TL-D3 Pro /JST-XH Protectors /4pin/JST_Main4P-c4.stl
14.8 x 20.0 x 5.70

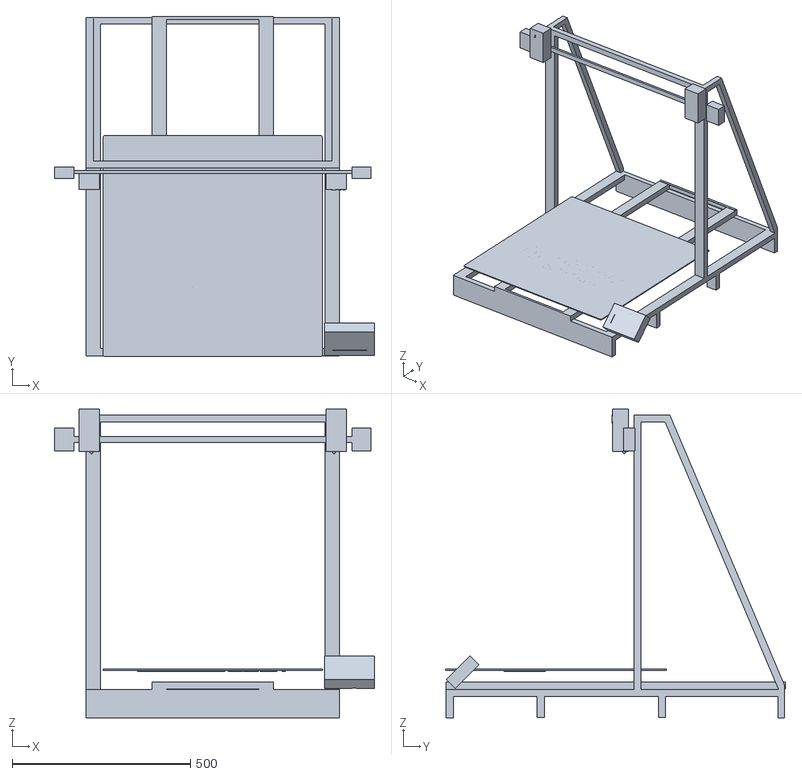
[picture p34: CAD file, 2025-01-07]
TL-D3 Cura Profiles/meshes/TL-D6Pro.stl
897.6 x 953.8 x 865.8

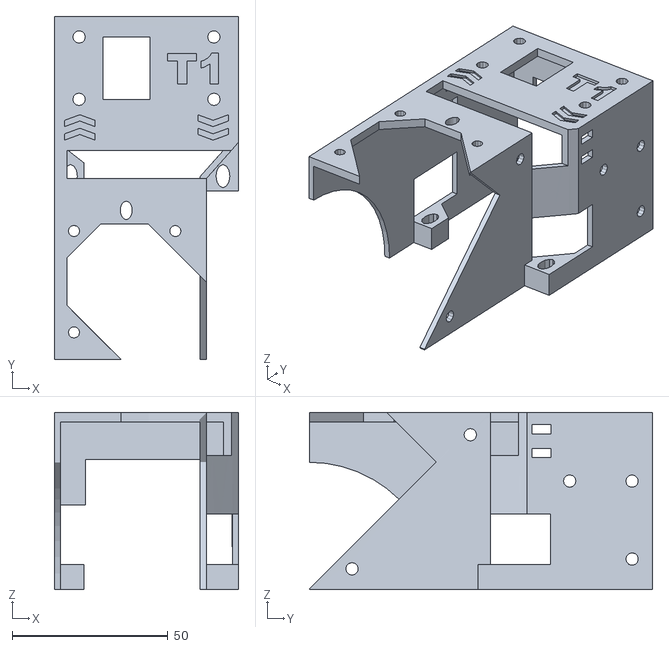
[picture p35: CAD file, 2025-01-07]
Useful STL Files for the TL-D3 Pro /5015 Fanduct/files/DC_T1_cover.stl
59.0 x 110.0 x 56.8

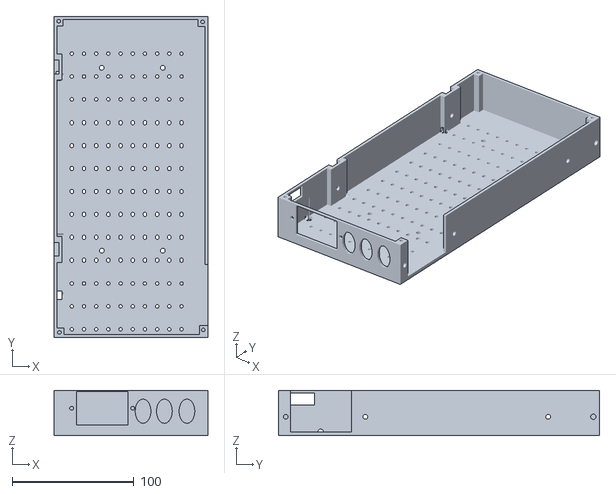
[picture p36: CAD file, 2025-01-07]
Useful STL Files for the TL-D3 Pro /BTT Super Case/SV03_PowerSupply_Case.stl
126.0 x 263.4 x 36.9

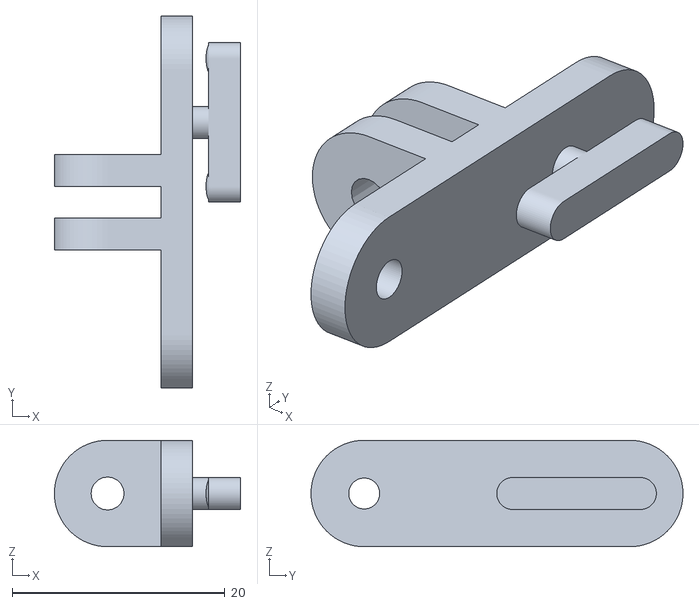
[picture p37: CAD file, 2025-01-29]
Useful STL Files for the TL-D3 Pro /Cameramount.stl
17.5 x 35.0 x 10.0

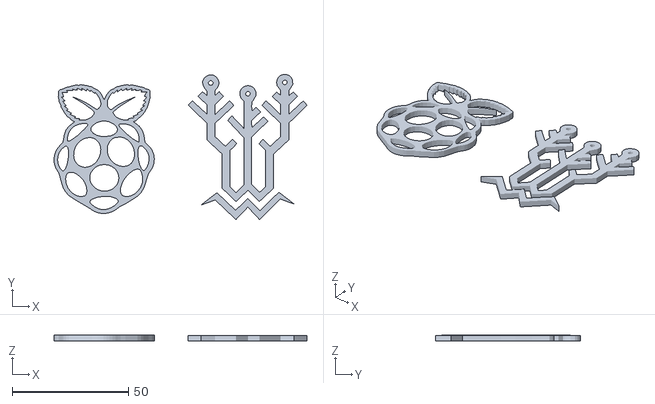
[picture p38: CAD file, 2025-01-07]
Useful STL Files for the TL-D3 Pro /Logos/PIandBTTLogo.stl
109.0 x 62.6 x 2.65

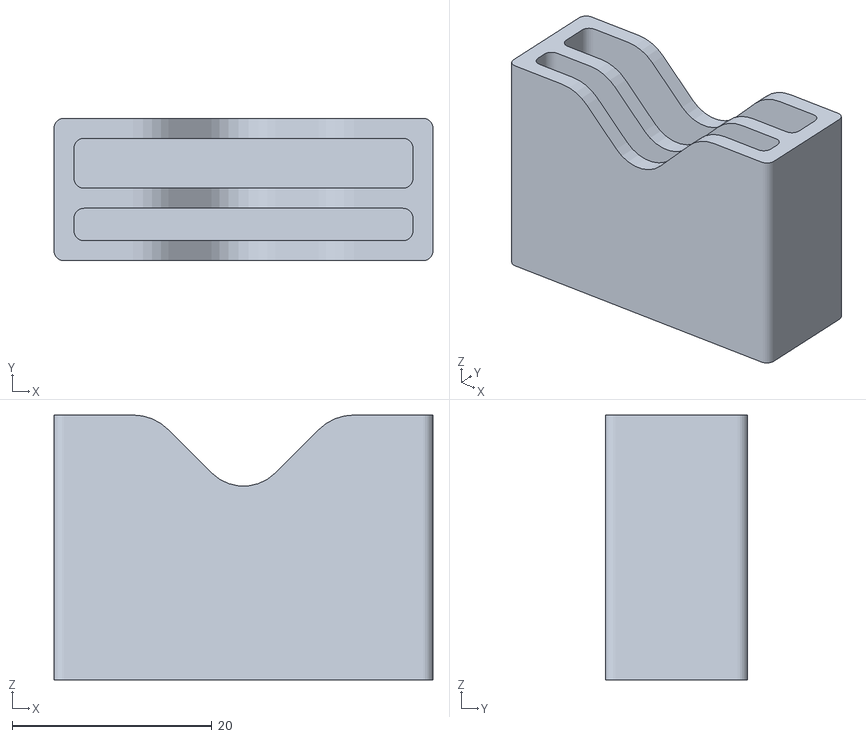
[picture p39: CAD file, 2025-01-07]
Useful STL Files for the TL-D3 Pro /Purge Bin w_ Modular Inserts/files/TLD3pro_Purge_Bin_Wiper_Insert.stl
37.9 x 14.2 x 26.5

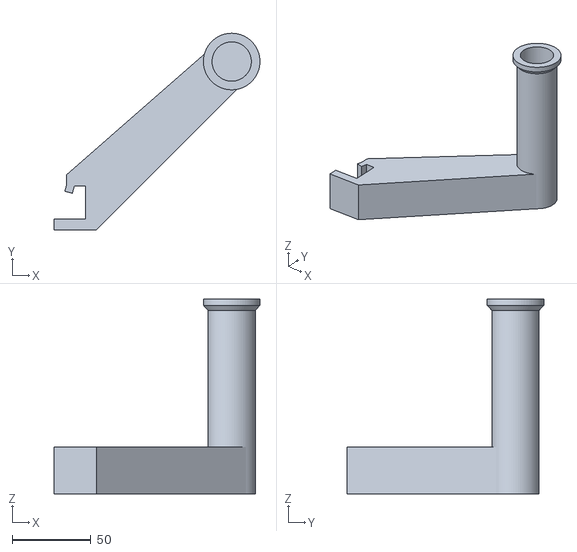
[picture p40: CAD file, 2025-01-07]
Useful STL Files for the TL-D3 Pro /Spool Holders/files/RH_Spool_Holder_Tenlog_TL-D3_Pro.stl
131.0 x 125.0 x 124.0

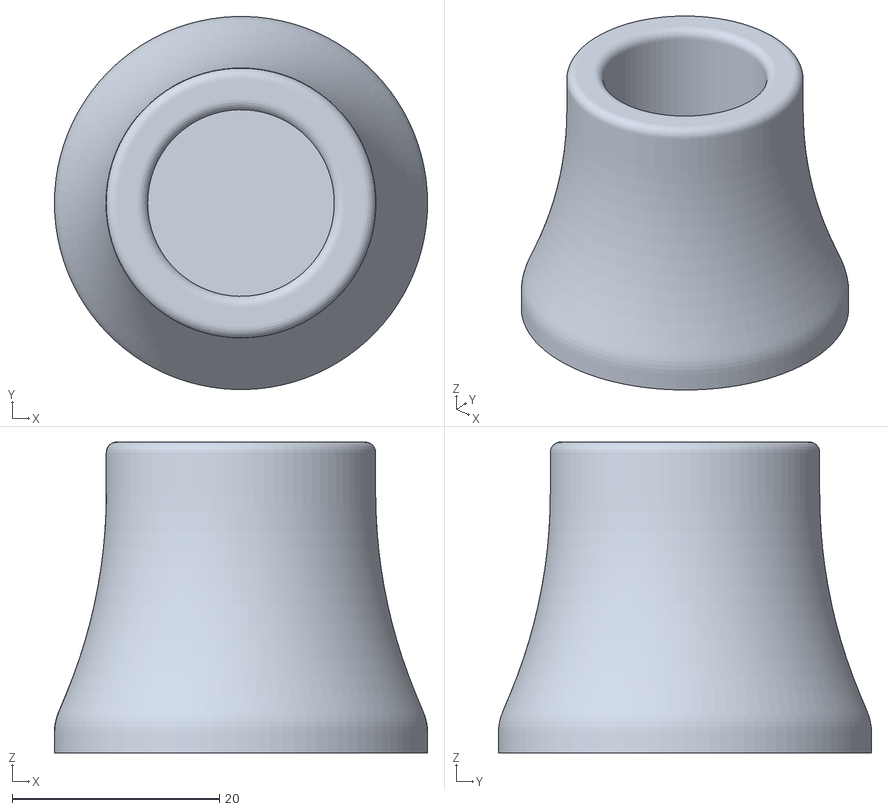
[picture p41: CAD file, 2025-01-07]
Useful STL Files for the TL-D3 Pro /Tenlog TL-D3 Pro TPU Foot/files/Tenlog_TL-D3_Pro_TPU_Foot.stl
36.0 x 36.0 x 30.0

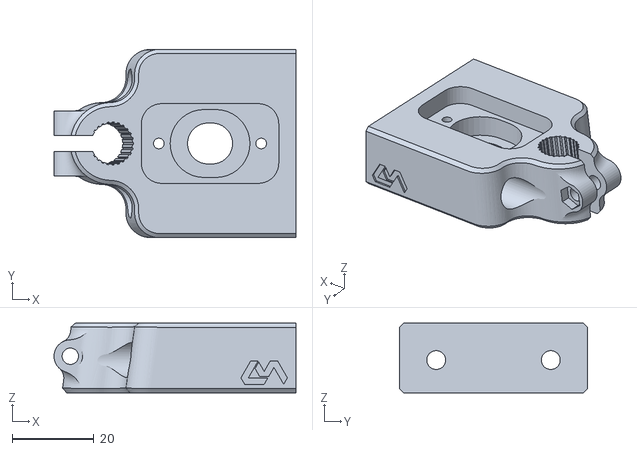
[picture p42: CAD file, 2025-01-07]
Useful STL Files for the TL-D3 Pro /tenlog-tl-d3-pro-z-stabilizer/Z_top_D10_RV01.STL
59.1 x 46.0 x 17.0

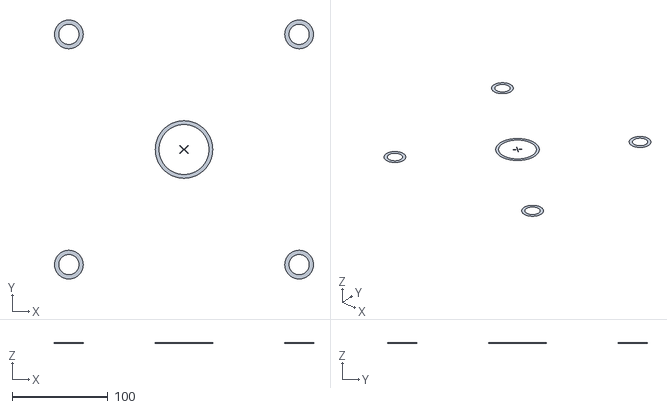
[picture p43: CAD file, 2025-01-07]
Useful STL Files for the TL-D3 Pro /Testing/Bed level and nozzle offset/files/TLD_BL1.stl
270.0 x 270.0 x 0.2

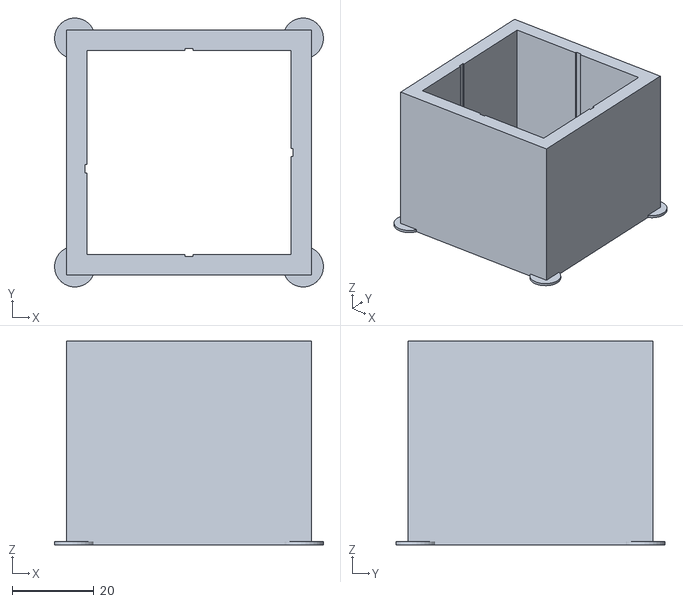
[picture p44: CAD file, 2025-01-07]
Useful STL Files for the TL-D3 Pro /Testing/square_tower.stl
66.0 x 65.9 x 50.0

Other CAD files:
TL-D3 Cura Profiles/meshes/TL-D4Pro.stl
Useful STL Files for the TL-D3 Pro /5015 Fanduct/files/DC_T0_fanduct_Text.stl
Useful STL Files for the TL-D3 Pro /BTT Super Case/SV03_Controller_RPI_Case.stl
Useful STL Files for the TL-D3 Pro /Filament guide.stl
TL-D3 Cura Profiles/meshes/TL-D3Pro.stl
TL-D3 Cura Profiles/meshes/TL-D5Pro.stl
Useful STL Files for the TL-D3 Pro /19_mm_wrench.stl
Useful STL Files for the TL-D3 Pro /5015 Fanduct/files/DC_T0_cover.stl
Useful STL Files for the TL-D3 Pro /5015 Fanduct/files/DC_T0_cover_Text.stl
Useful STL Files for the TL-D3 Pro /5015 Fanduct/files/DC_T0_fanduct.stl
Useful STL Files for the TL-D3 Pro /5015 Fanduct/files/DC_T1_cover_Text.stl
Useful STL Files for the TL-D3 Pro /5015 Fanduct/files/DC_T1_fanduct.stl
Useful STL Files for the TL-D3 Pro /5015 Fanduct/files/DC_T1_fanduct_Text.stl
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

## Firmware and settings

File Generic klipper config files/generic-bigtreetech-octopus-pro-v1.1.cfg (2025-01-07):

# This file contains common pin mappings for the BigTreeTech Octopus
# Pro v1.1 board.

# Important! Do not use this config with an Octopus Pro v1.0 board nor
# non-Pro board.

# To use this config, during "make menuconfig", select "Enable
# low-level configuration options", select the STM32H723
# micro-controller, select a "128KiB bootloader", and select a "25Mhz
# crystal".

# See docs/Config_Reference.md for a description of parameters.

# Driver0
[stepper_x]
step_pin: PF13
dir_pin: PF12
enable_pin: !PF14
microsteps: 16
rotation_distance: 40
endstop_pin: PG6
position_endstop: 0
position_max: 200
homing_speed: 50

# Driver1
[stepper_y]
step_pin: PG0
dir_pin: PG1
enable_pin: !PF15
microsteps: 16
rotation_distance: 40
endstop_pin: PG9
position_endstop: 0
position_max: 200
homing_speed: 50

# Driver2
[stepper_z]
step_pin: PF11
dir_pin: PG3
enable_pin: !PG5
microsteps: 16
rotation_distance: 8
endstop_pin: PG10
position_endstop: 0.5
position_max: 200

# Driver3
# The Octopus only has 4 heater outputs which leaves an extra stepper
# This can be used for a second Z stepper, dual_carriage, extruder co-stepper,
# or other accesory such as an MMU
#[stepper_]
#step_pin: PG4
#dir_pin: PC1
#enable_pin: !PA2
#endstop_pin: PG11
#...

# Driver4
[extruder]
step_pin: PF9
dir_pin: PF10
enable_pin: !PG2
microsteps: 16
rotation_distance: 33.500
nozzle_diameter: 0.400
filament_diameter: 1.750
heater_pin: PA0 # HE0
sensor_pin:  PF4 # T0
sensor_type: EPCOS 100K B57560G104F
control: pid
pid_Kp: 22.2
pid_Ki: 1.08
pid_Kd: 114
min_temp: 0
max_temp: 250

#[filament_switch_sensor material_0]
#switch_pin: PG12

# Driver5
#[extruder1]
#step_pin: PC13
#dir_pin: PF0
#enable_pin: !PF1
#heater_pin: PA3 # HE1
#sensor_pin: PF5 # T1
#...

#[filament_switch_sensor material_1]
#switch_pin: PG13

# Driver6
#[extruder2]
#step_pin: PE2
#dir_pin: PE3
#enable_pin: !PD4
#heater_pin: PB0 # HE2
#sensor_pin: PF6 # T2
#...

#[filament_switch_sensor material_2]
#switch_pin: PG14

# Driver7
#[extruder3]
#step_pin: PE6
#dir_pin: PA14
#enable_pin: !PE0
#heater_pin: PB11 # HE3
#sensor_pin: PF7 # T3
#...

#[filament_switch_sensor material_3]
#switch_pin: PG15

[heater_bed]
heater_pin: PA1
sensor_pin: PF3 # TB
sensor_type: ATC Semitec 104GT-2
control: watermark
min_temp: 0
max_temp: 130

[fan]
pin: PA8

#[heater_fan fan1]
#pin: PE5

#[heater_fan fan2]
#pin: PD12

#[heater_fan fan3]
#pin: PD13

#[heater_fan fan4]
#pin: PD14

#[controller_fan fan5]
#pin: PD15

[mcu]
serial: /dev/serial/by-id/usb-Klipper_Klipper_firmware_12345-if00
# CAN bus is also available on this board

[printer]
kinematics: cartesian
max_velocity: 300
max_accel: 3000
max_z_velocity: 5
max_z_accel: 100

########################################
# TMC2209 configuration
########################################

#[tmc2209 stepper_x]
#uart_pin: PC4
##diag_pin: PG6
#run_current: 0.800
#stealthchop_threshold: 999999

#[tmc2209 stepper_y]
#uart_pin: PD11
##diag_pin: PG9
#run_current: 0.800
#stealthchop_threshold: 999999

#[tmc2209 stepper_z]
#uart_pin: PC6
##diag_pin: PG10
#run_current: 0.650
#stealthchop_threshold: 999999

#[tmc2209 stepper_]
#uart_pin: PC7
##diag_pin: PG11
#run_current: 0.650
#stealthchop_threshold: 999999

#[tmc2209 extruder]
#uart_pin: PF2
#run_current: 0.800
#stealthchop_threshold: 999999

#[tmc2209 extruder1]
#uart_pin: PE4
#run_current: 0.800
#stealthchop_threshold: 999999

#[tmc2209 extruder2]
#uart_pin: PE1
#run_current: 0.800
#stealthchop_threshold: 999999

#[tmc2209 extruder3]
#uart_pin: PD3
#run_current: 0.800
#stealthchop_threshold: 999999

########################################
# TMC2130 configuration
########################################

#[tmc2130 stepper_x]
#cs_pin: PC4
#spi_bus: spi1
##diag1_pin: PG6
#run_current: 0.800
#stealthchop_threshold: 999999

#[tmc2130 stepper_y]
#cs_pin: PD11
#spi_bus: spi1
##diag1_pin: PG9
#run_current: 0.800
#stealthchop_threshold: 999999

#[tmc2130 stepper_z]
#cs_pin: PC6
#spi_bus: spi1
##diag1_pin: PG10
#run_current: 0.650
#stealthchop_threshold: 999999

#[tmc2130 stepper_]
#cs_pin: PC7
#spi_bus: spi1
##diag1_pin: PG11
#run_current: 0.800
#stealthchop_threshold: 999999

#[tmc2130 extruder]
#cs_pin: PF2
#spi_bus: spi1
#run_current: 0.800
#stealthchop_threshold: 999999

#[tmc2130 extruder1]
#cs_pin: PE4
#spi_bus: spi1
#run_current: 0.800
#stealthchop_threshold: 999999

#[tmc2130 extruder2]
#cs_pin: PE1
#spi_bus: spi1
#run_current: 0.800
#stealthchop_threshold: 999999

#[tmc2130 extruder3]
#cs_pin: PD3
#spi_bus: spi1
#run_current: 0.800
#stealthchop_threshold: 999999

[board_pins]
aliases:
    # EXP1 header
    EXP1_1=PE8, EXP1_2=PE7,
    EXP1_3=PE9, EXP1_4=PE10,
    EXP1_5=PE12, EXP1_6=PE13,    # Slot in the socket on this side
    EXP1_7=PE14, EXP1_8=PE15,
    EXP1_9=<GND>, EXP1_10=<5V>,

    # EXP2 header
    EXP2_1=PA6, EXP2_2=PA5,
    EXP2_3=PB1, EXP2_4=PA4,
    EXP2_5=PB2, EXP2_6=PA7,      # Slot in the socket on this side
    EXP2_7=PC15, EXP2_8=<RST>,
    EXP2_9=<GND>, EXP2_10=PC5

# See the sample-lcd.cfg file for definitions of common LCD displays.

# A [probe] section can be defined instead with a pin: setting identical
# to the sensor_pin: for a bltouch
#[bltouch]
#sensor_pin: PB7
#control_pin: PB6
#z_offset: 0

#[neopixel my_neopixel]
#pin: PB10

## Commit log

2025-01-07 Cura Profiles
    [TL-D3Pro.stl, TL-D4Pro.stl, TL-D5Pro.stl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]
2025-01-07 generic config files
    generic klipper config files for reference
    [generic-bigtreetech-octopus-pro-v1.1.cfg, sample-bigtreetech-exp-mot.cfg, sample-idex.cfg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]
2025-01-07 stl files
    [BTT_Octopus_Logo_v3.stl, DC_T0_cover.stl, DC_T0_cover_Text.stl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]
2025-01-08 updated stl files
    [19_mm_wrench.stl, BTT_Octopus_Logo_v3.stl, BTT_Octopus_Mount.stl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]
